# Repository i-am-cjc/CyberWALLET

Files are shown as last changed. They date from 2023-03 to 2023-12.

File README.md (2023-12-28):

# CyberWALLET
Inspired by the USB Rubber Ducky / BadUSB, but in a different formfactor that I might actually carry and use.

## Hardware
The current iteration of the CyberWALLET is a Raspberry Pi Pico, and an SSD1306 0.9inch 128x32 screen. There are two buttons on the front that will be used for menu navigation as well as interaction in scripts.

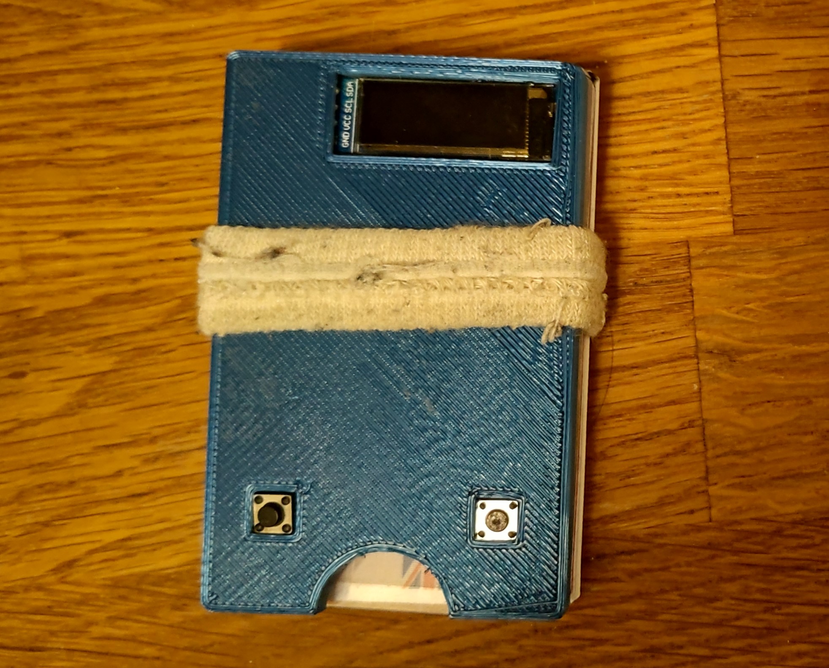
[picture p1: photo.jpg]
Title


Multiple scripts can be loaded and then selected upon boot using the buttons on the device.

## Scripting Language
The CyberWALLET uses a pretty simple scripting language, again inspired mostly by the Hak5 USB Rubber Ducky, but with some other stuff based around the buttons on the front of the device.

* TYPE <string> - Types out the string, but doesn't press enter
* RTYPE <string> - Types out the string and presses enter (ps RType is a great game)
* SLEEP <float> - Sleeps for the float number of seconds
* RSLEEP <int:x>,<int:y> - Sleeps for random number of seconds between the x and y
* DELAY <float> - Sets the default sleep time between commands (default: 0.1)
* RETURN - Presses Return
* TAB - Presses Tab
* MOD4 <key>- Presses the MOD4 / Windows key with the optional key (i.e. "MOD4 l" would lock a windows machine)
* CTRL <key> - Presses the control key with an optional key (i.e. "CTRL a" would select all in a lot of applications)
* MOUSE <int:x>,<int:y> - Moves the Mouse by x,y
* CLICK - Clicks the left mouse
* SET <variable> - Sets a variable to true
* UNSET <variable> - Sets a variable to false
* LABEL <string> - A label in code to jump to
* JUMP <LABEL> - Jumps to a specific label
* VJUMP <variable> <label> - Jumps to label is variable is set, otherwise carries on down the script
* BJUMP <target> - waits for a button press. If the left button is pressed, JUMP to target, otherwise carry on down the script.
* REM <string> - A comment
* SCREEN <string> - Writes the string to the internal screen, great for debugging / amusement.
* INC <filename> - Saves the current state of the file and includes another file for command tasks. The filename should not include the .card extension, variables set in one file are present throughout the others and are not cleared when switching between files.

### Hello World!

Here is an example script that will open up notepad on a windows computer, and write hello world.

```
DELAY 1
MOD4 r
RTYPE notepad
TYPE Hello World
```

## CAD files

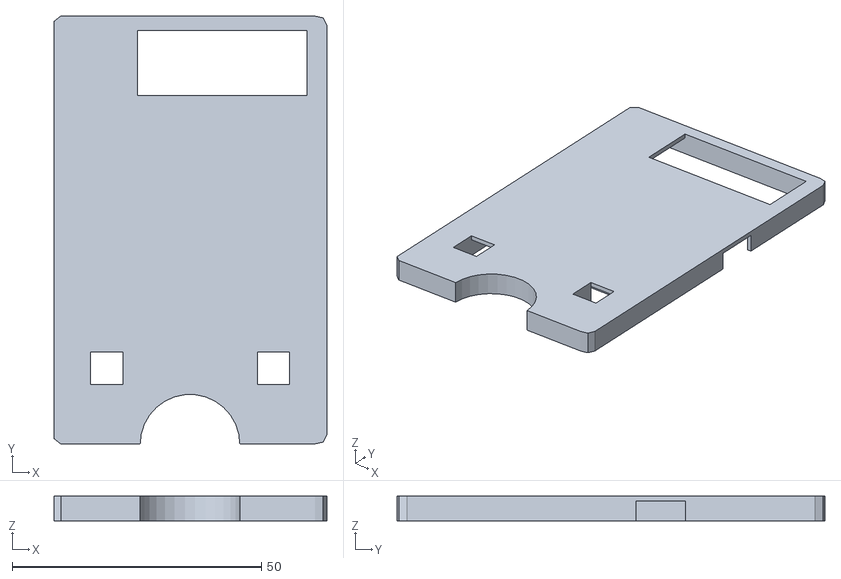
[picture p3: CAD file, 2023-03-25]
STL/main_plate.stl
54.8 x 85.9 x 5.00

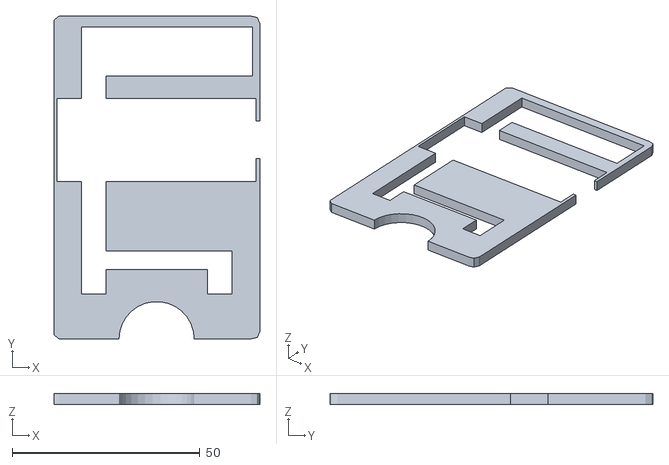
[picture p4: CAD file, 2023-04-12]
STL/spacer.stl
54.8 x 85.9 x 3.00

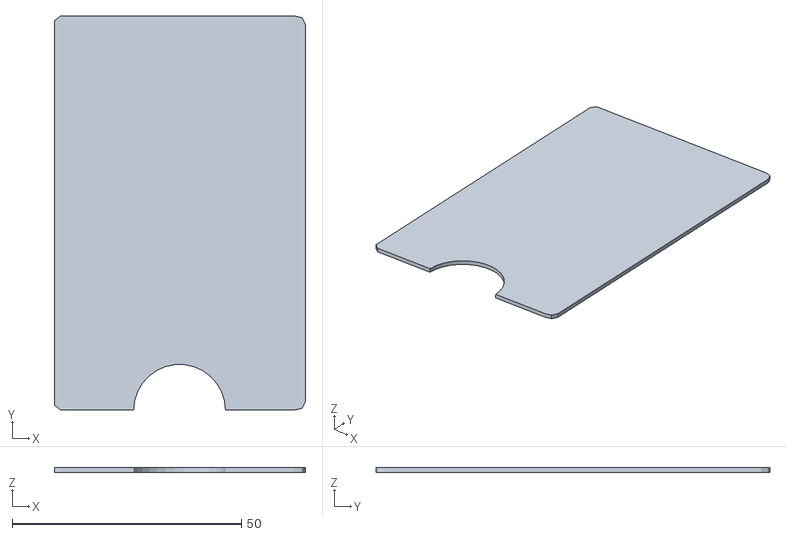
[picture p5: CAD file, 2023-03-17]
STL/front_card.stl
54.8 x 85.9 x 1.00

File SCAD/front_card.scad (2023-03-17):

// 55x86x.8mm
difference() {
    minkowski() {
        cylinder(h=.5, r=2);
        cube([51, 82, .5]);
    }

    translate([25.5, -2, -1]) {
        cylinder(h=2, d=20);
    }
}

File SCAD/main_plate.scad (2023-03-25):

// 55x86x.8mm

difference () {
    minkowski() {
        cylinder(h=2.5, r=2);
        cube([51, 82, 2.5]);
    }

    translate([25.5, -2, -1]) {
        cylinder(h=10, d=20);
    }
    // 86 / 2 43 (-11) 32
    translate([-1, 40, 0]) {
        color("red") {
            cube([53,22,4]);
        }
        translate([0, 6, 0]) {
            cube([200, 10, 4]);
        }
    }
    
    // middle 10 out of 22
    
    
    
// i2c screen
// 30.00 mm × 12.00 mm × 2.00 mm 
    translate([8, 68, 0]) {
        cube([43 , 13, 4]);
        translate([7,0,4]) {
            cube([34,13,4]);
        }
    }
    
    // buttons 6.0 x 6.2 tall legs down
    // 4.0 tall 5 tall to button 3.4diam button
    translate([5.5, 10, 0]) {
        cube([6.5, 6.5, 5]);
    }
    
    translate([55-5.5-6.5-4, 10, 0]) {
        cube([6.5, 6.5, 5]);
    }
    
    // wiring gaps for buttons
    translate([5.5, 16.5, 0]) {
        cube([40, 5, 4]);
        
            cube([6.5, 64.5, 4]);
        
    }
}

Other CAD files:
SCAD/spacer.scad

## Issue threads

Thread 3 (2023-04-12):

Improve messages written to screen

i-am-cjc, 2023-04-12:
If a message is too long, it just doesn't appear on the screen.

Maybe a second thread that can manage the messages written to screen and scroll them or something?

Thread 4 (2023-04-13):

CLICK command

i-am-cjc, 2023-04-13:
Command to Click a Mouse button

right / left click maybe?

i-am-cjc, 2023-04-13:
https://docs.circuitpython.org/projects/hid/en/latest/api.html#adafruit-hid-mouse-mouse

Closed 2023-04-13.

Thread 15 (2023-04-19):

Improve Button Handling

i-am-cjc, 2023-04-19:
Buttons are currently just polled in the menu every x milliseconds. Meaning if you press and release between these polls, the button press is not logged and is annoying.

Really it should use a debounce mechanic so that it can be pressed at any time, but not again until after x ms.

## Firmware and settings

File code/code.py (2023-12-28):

import usb_hid
from adafruit_hid.keyboard import Keyboard
from adafruit_hid.keyboard_layout_us import KeyboardLayoutUS
from adafruit_hid.keycode import Keycode
from adafruit_hid.mouse import Mouse
import time
import random

import board
import digitalio

import displayio
import terminalio
import busio
from adafruit_display_text import label
import adafruit_displayio_ssd1306

import os

displayio.release_displays()

i2c = busio.I2C(scl=board.GP27, sda=board.GP26)
display_bus = displayio.I2CDisplay(i2c, device_address=0x3C)

WIDTH = 128
HEIGHT = 32
BORDER = 5

display = adafruit_displayio_ssd1306.SSD1306(display_bus, width=WIDTH, height=HEIGHT)

# Make the display context

splash = displayio.Group()
display.show(splash)

led = digitalio.DigitalInOut(board.LED)
led.direction = digitalio.Direction.OUTPUT
led.value = False

left_button = digitalio.DigitalInOut(board.GP12)
left_button.switch_to_input(pull=digitalio.Pull.DOWN)

right_button = digitalio.DigitalInOut(board.GP13)
right_button.switch_to_input(pull=digitalio.Pull.DOWN)

# Set up the keyboard and mouse objects
keyboard = Keyboard(usb_hid.devices)
keyboard_layout = KeyboardLayoutUS(keyboard)
mouse = Mouse(usb_hid.devices)

def update_screen( lines ):

    line1, line2 = lines
    splash = displayio.Group()
                
    # Make the display context
    text_area = label.Label(
        terminalio.FONT, text=line2, color=0xFFFFFF, x=4, y=HEIGHT-6
    )
    splash.append(text_area)
    
    text_area_top = label.Label(
        terminalio.FONT, text=line1, color=0xFFFFFF, x=4, y=4
    )
    splash.append(text_area_top)
    
    display.show(splash)
    display.refresh()

def run():
    STATUS = "CyberWALLET"
    #displayio.release_displays()

    # Initialize the program counter to zero
    program_counter = 0

    # 0 = MENU, 1 = RUNNING
    STATE = 0
    FILENAME = ""

    DELAY = 0.1

    VARS = {}
    STACK = []

    # Track if we have already run the autorun file
    AUTORAN = False

    while True:
        VARS = {}
        if STATE == 0:
            files = []
            for f in os.listdir("./cards"):
                if f.endswith('.card'):
                    files.append(f)
            files.sort()
            index = 0
            FILENAME = files[index]
            
            if "autorun.card" in files and not AUTORAN:
                FILENAME = "autorun.card"
                STATE = 1
                AUTORAN = True

            while STATE == 0:
                update_screen( ("Choose Card:", FILENAME[:-5]))
                if (right_button.value):
                    STATE = 1
                elif (left_button.value):
                    index += 1
                    if index >= len(files):
                        index = 0
                    FILENAME = files[index]
                        
                time.sleep(0.1)
        elif STATE == 1:
            # Read the list of commands from a text file
            with open("./cards/" + FILENAME, 'r') as file:
                commands = file.read().splitlines()
            top_text = ""

            program_counter = 0
            while program_counter < len(commands):
                need_to_sleep = False
                command = commands[program_counter]

                update_screen( (STATUS, str(program_counter) + " " + command))
                
                if command.startswith('TYPE'):
                    # Extract the text to type from the command and type it using the keyboard
                    text = command[5:]
                    keyboard_layout.write(text)
                    need_to_sleep = True
                elif command.startswith('SLEEP'):
                    # Extract the sleep duration from the command and sleep for that amount of time
                    duration = float(command[6:])
                    time.sleep(duration)
                elif command.startswith("DELAY"):
                    DELAY = float(command[6:])
                elif command.startswith("RSLEEP"):
                    x, y = command[6:].split(',')
                    time.sleep(random.uniform(int(x), int(y) + 1))
                elif command.startswith("RTYPE"):
                    text = command[6:]
                    keyboard_layout.write(text)
                    time.sleep(0.1)
                    keyboard.send(Keycode.ENTER)
                    need_to_sleep = True
                elif command == 'RETURN':
                    # Press the return key using the keyboard
                    keyboard.send(Keycode.ENTER)
                    need_to_sleep = True
                elif command == "TAB":
                    keyboard.send(Keycode.TAB)
                    need_to_sleep = True
                elif command.startswith('MOD4'):
                    # Press the windows key using the keyboard
                    keyboard.press(Keycode.WINDOWS)
                    if len(command) > 4:
                        k = command[5:6]
                        keyboard_layout.write(k)
                    keyboard.release(Keycode.WINDOWS)
                    need_to_sleep = True
                elif command.startswith('CTRL'):
                    keyboard.press(Keycode.CONTROL)
                    if len(command) > 4:
                        k = command[5:6]
                        keyboard_layout.write(k)
                    keyboard.release(Keycode.CONTROL)
                    need_to_sleep = True
                elif command.startswith('MOUSE'):
                    x, y = command[6:].split(',')
                    mouse.move(int(x), int(y))
                    need_to_sleep = True
                elif command.startswith('CLICK'):
                    mouse.click(Mouse.LEFT_BUTTON)
                    need_to_sleep = True
                elif command.startswith('JUMP'):
                    # Extract the line number to jump to from the command and update the program counter
                    jump_target = command[5:]
                    target = 0
                    for line in commands:
                        if line == "LABEL " + jump_target:
                            program_counter = target
                        target += 1
                    continue
                elif command.startswith("SET"):
                    var = command[4:]
                    VARS[var] = True
                elif command.startswith("UNSET"):
                    var = command[6:]
                    if var in VARS:
                        del VARS[var]
                elif command.startswith("VJUMP"):
                    var, jump_target = command[6:].split(" ")
                    if var in VARS:
                        target = 0
                        for line in commands:
                            if line == "LABEL " + jump_target:
                                program_counter = target
                            target += 1
                    else:
                        program_counter += 1
                    continue
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

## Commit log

2023-03-17 Initial Commit
    I've not got the screen yet so this is a simple simple version
    [front_card.scad, front_card.stl, main_plate.scad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]
2023-03-21 Update code.py
    Added LED toggle (for visual debugging)
2023-03-21 Update JIGGLE.cy
    Added LED toggling to the jiggler script
2023-03-22 Update main_plate.stl
    Updated STL
    [main_plate.stl]
2023-03-25 Update boot.py
    Disable usb / serial if button is not pressed
2023-03-25 Updates to main plate and STL
    Update to the main plate to move the screen to the side and move the pico up a little.
    [main_plate.scad, main_plate.stl]
2023-03-25 Updates or something...
    Lots of updates, I am not a professional software dev
    * Screen now in use
    * buttons in use
    * Menu to select scrript to run
    * Probably more, who cares?
2023-03-27 Update code.py
    Fixed issues with moving to scripts folder
    [code.py]
2023-03-27 Update boot.py
    Meant to be using the correct button
2023-04-12 Added a spacer
    This is because I soldered it too thick, so for now add a spacer to the design
    [spacer.scad, spacer.stl]
2023-04-15 Update code.py
    Doesn't display the .cy file extension now on the script selection screen
    [code.py]
2023-04-16 INC implemented
    Can now include other files for common actions (such as loading a powershell window, or notepad for demonstration files)
2023-10-25 Stupid case sensitive names on windows
2023-10-25 Stupid case sensitive names on windows2
